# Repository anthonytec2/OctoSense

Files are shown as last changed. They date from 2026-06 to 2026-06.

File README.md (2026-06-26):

<!-- ======================= OctoSense ======================= -->
<p align="center">
  OctoSense
</p>

<p align="center"><b>Self-Supervised Learning for Multimodal Robot Perception</b></p>

<p align="center">
  
  
  
  
</p>

<p align="center">
  <video src="https://github.com/user-attachments/assets/d7269059-0989-4554-a36d-4d6e72473253"
         autoplay loop muted playsinline controls width="100%">
    <a href="https://huggingface.co/datasets/anthonytec2/OctoSense/resolve/main/assets/hero.mp4">Watch the OctoSense overview video</a>
  </video>
</p>

---

**OctoSense** is a multimodal dataset spanning a car, boat, and quadruped on a shared sensor platform. The
bulk is large-scale **driving**: **59 hours / 2,474 km / 8.43 TB** of time-synchronized data from
**stereo RGB + event cameras, LiDAR, thermal, IMU, RTK-GPS, and the vehicle CAN bus**, recorded across
urban, suburban, and rural roads from sunrise to night and through degraded sensors, with
ground truth for **depth, optical flow, semantic segmentation, and ego-motion**. We also include
sequences recorded on a **boat** and a **Unitree quadruped** using the same sensor platform. Every sequence is
captured by a fully **open-source sensor platform** and processed with the pipeline in this repo.

> **Getting started with OctoSense data:** the
> [**getting-started notebook**](octosense_quickstart.ipynb) downloads a sequence and walks
> through every modality. Open it with **zero setup** in
> [Colab](https://colab.research.google.com/drive/11hBm5dH--7HueAFCKtaAFnDAJul-52fb?usp=sharing), or
> run it locally after the install below (activate the env first: `conda activate octosense`).
> 
> **The dataset (sensor specs, HDF5 schema, per-sequence metadata, and downloads) lives on the
> [Hugging Face dataset page](https://huggingface.co/datasets/anthonytec2/OctoSense).**
> This repository is the **tooling around it**: how the data is collected, visualized, and produced.

## Installation

OctoSense has two parts with separate environments:

- **Data acquisition + conversion**: the ROS 2 capture stack ([`OctoSense/`](OctoSense/)) and the
  raw-bag conversion run in a **custom-built Docker container** (ROS 2 Jazzy + source-built FFmpeg);
  only the raw-bag conversion in `data_processing/timesync/` needs the ROS 2 container. See
  **[OctoSense/README.md](OctoSense/README.md)** to build and run it.
- **Data loading + processing**: loading/visualizing the data, deriving flow, and the
  depth/segmentation ground-truth and semantic-search tooling run in the **conda env** below.

```bash
git clone https://github.com/anthonytec2/OctoSense.git
cd OctoSense
conda env create -f environment.yml      # installs Python, FFmpeg, and a CPU build of PyTorch
conda activate octosense
```

This installs a **CPU** build of PyTorch + torchcodec by default. On a **CUDA GPU** (faster video
decoding and model inference) reinstall the **GPU wheels** for torch, torchvision, and torchcodec
after activating, picking versions per the
[torchcodec compatibility table](https://github.com/meta-pytorch/torchcodec#compatibility-with-torch-versions):

```bash
pip install 'torch==2.12.*' 'torchvision==0.27.*' 'torchcodec>=0.14' \
  --index-url https://download.pytorch.org/whl/cu130
```

## Download the dataset

The full dataset (8+ TB) lives on the
[Hugging Face dataset page](https://huggingface.co/datasets/anthonytec2/OctoSense).
Use **`download_octosense.py`** (repo root) to grab a subset by platform, sequence, and modality,
and skip the raw event streams (`events.h5`, ~78% of each sequence's bytes):

```bash
pip install huggingface_hub

# all car sequences (everything)
python download_octosense.py --platform car --out ./octosense

# the same, but skip the raw event streams (events.h5, ~78% of the bytes)
python download_octosense.py --platform car --no-events

# one sequence, only the core LiDAR/IMU/GPS h5 + depth + segmentation
python download_octosense.py --sequence rosbag2_2026_01_04-13_51_24 --modalities data,depth,seg

# download_octosense.py just wraps huggingface_hub, so you can also use the HF CLI directly
hf download anthonytec2/OctoSense --repo-type dataset --local-dir ./octosense
```

`--modalities` picks from `data, events, captions, depth, seg, rgb, ir`.

Five entry points into OctoSense from this repository, start with the notebook:

### Start here: the quickstart notebook ([`octosense_quickstart.ipynb`](octosense_quickstart.ipynb))
The [getting-started notebook](octosense_quickstart.ipynb) downloads a sequence and walks
through every modality (LiDAR, stereo RGB, events, depth, segmentation, GPS, IMU, CAN, and captions).
Open it with **zero setup** in
[Colab](https://colab.research.google.com/drive/11hBm5dH--7HueAFCKtaAFnDAJul-52fb?usp=sharing), or run
it locally after the install above (activate the env first: `conda activate octosense`).

### Visualize a sequence ([`data_processing/viz/`](data_processing/viz/))

<p align="center">
  <video src="https://github.com/user-attachments/assets/0f6a7751-e6b5-42f4-a3f9-07839ff3b1ef"
         autoplay loop muted playsinline controls width="100%">
    Rerun viewer scrubbing an OctoSense sequence across every modality.
  </video>
</p>

Generate a **[Rerun](https://rerun.io)** recording from a downloaded sequence with the script below,
then open the resulting `.rrd` in the Rerun viewer to scrub every modality on one shared timeline
(LiDAR, stereo RGB, reconstructed event video, depth, GPS track, IMU, CAN signals, and captions) with
a bundled viewer layout:

```bash
python data_processing/viz/rerun_viz.py --dir <sequence_dir>
```

### Search the dataset in natural language ([`data_processing/sem_search/`](data_processing/sem_search/))

<p align="center">
  OctoSense semantic-search web UI
</p>
<p align="center"><sub>The <code>serve</code> web UI: a natural-language query returning ranked clips with scores and scene captions.</sub></p>

Every 5s of image sensor data is captioned and embedded into a hybrid **FAISS + BM25** index, so you can find moments
across all 2,474 km by description ("a car turning left at dusk", "wet road at night", "pedestrian
crossing"). Download the prebuilt index from the dataset and query it from the CLI
(CPU works; a GPU just speeds up the query encoder):

```bash
# 1) prebuilt search index (~700 MB) from the dataset
hf download anthonytec2/OctoSense --repo-type dataset --include "semantic_search/*" --local-dir ./octosense

# 2) natural-language query -> ranked sequences + timestamps (run from data_processing/)
cd data_processing
python -m sem_search.main query "a car turning left at dusk" --index-dir ../octosense/semantic_search

# 3) or browse results in a web UI (matching video clips in the browser at http://localhost:8000)
#    set DATA_BASE_PATH so the UI can play each result's clip (see note below)
DATA_BASE_PATH=./octosense/car python -m sem_search.main serve --index-dir ../octosense/semantic_search --port 8000
```

First run pulls the **Qwen3-Embedding** query encoder. Searching needs no video, but to **play the
matching clips** in the web UI, set the **`DATA_BASE_PATH`** env var to the dataset root that holds
`<session>/<bag>/{img_left.mp4, data.h5}` (e.g. `./octosense/car`); the clip/thumbnail endpoints read
`img_left.mp4` from there per request. Results can come from any sequence, so a clip only plays if
that sequence's `img_left.mp4` is present under `DATA_BASE_PATH` (others return 404; the text results
still show). For how the index is built, see the
**[`sem_search` stage details](data_processing/README.md)**.

### Collect your own data ([`OctoSense/`](OctoSense/))
Everything to reproduce the sensor platform and record your own synchronized data: the ROS 2 (Jazzy) capture
stack, **hardware PPS time-sync** (Teensy firmware + KiCad SyncBoard distributing a
pulse-per-second to every sensor), the mechanical **CAD**, the containerized capture environment, and
a web monitor to watch per-sensor health and start/stop recording.
**[Build and run instructions](OctoSense/README.md)**

<table align="center">
  <tr>
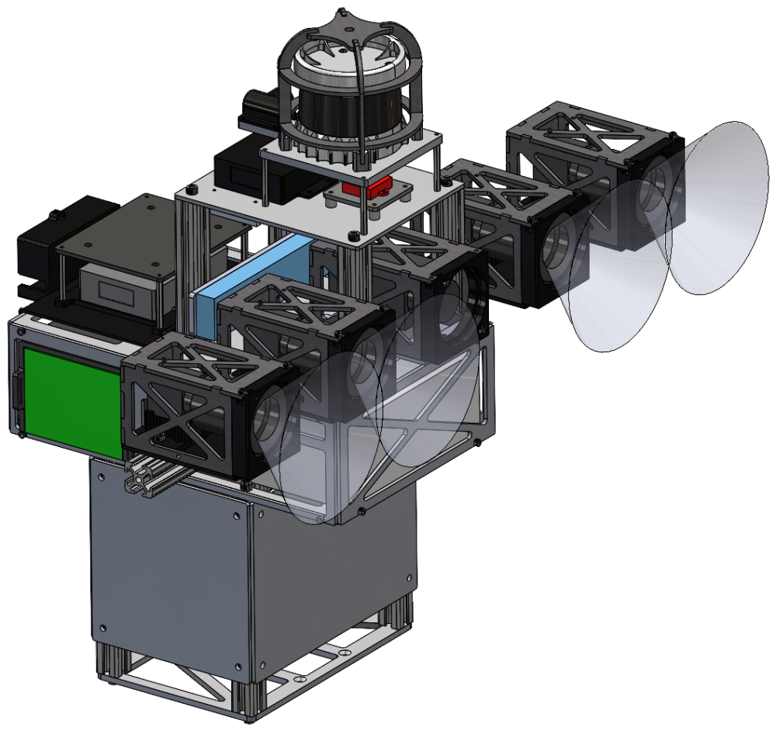
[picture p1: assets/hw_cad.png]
OctoSense sensor platform (CAD)
    <td align="center"></td>
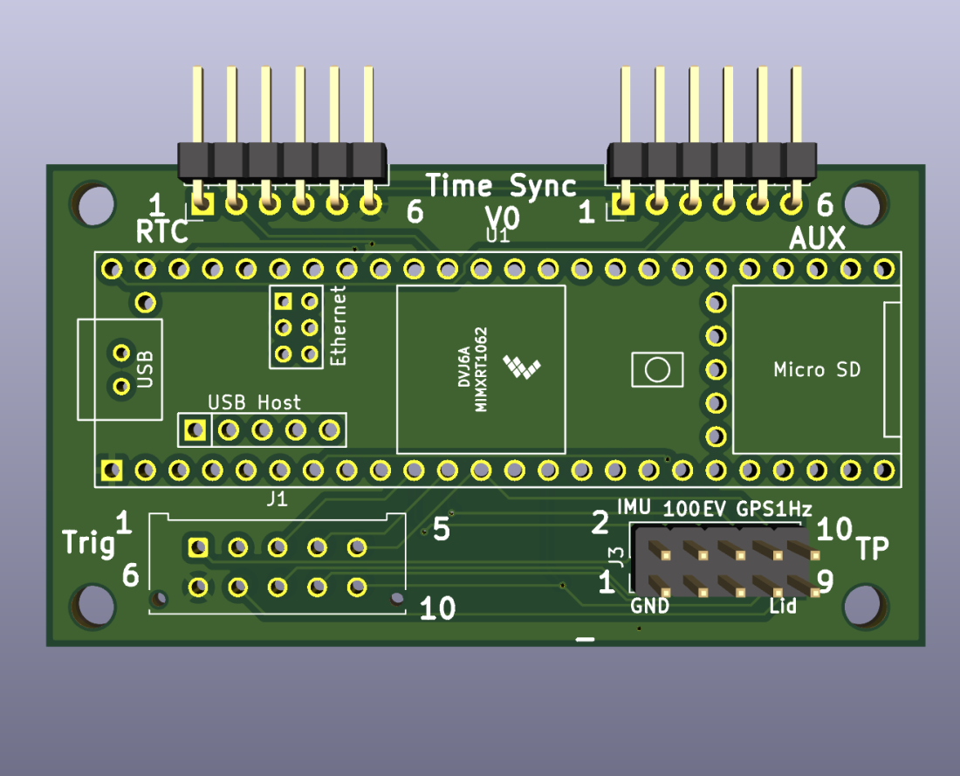
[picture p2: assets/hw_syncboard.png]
SyncBoard with the Teensy PPS clock
    <td align="center"></td>
  </tr>
  <tr>
    <td align="center"><sub>OctoSense Sensor Platform (CAD)</sub></td>
    <td align="center"><sub>Time Synchronization Custom PCB</sub></td>
  </tr>
</table>

### Process ROS2 Bags into OctoSense ([`data_processing/`](data_processing/))
The pipeline that turns a raw ROS 2 bag into the released sequences, as independent stages:
**`timesync`** (PPS clock-sync of all sensors to per-bag HDF5 + H.265 video), **`lidar_cal`**
(LiDAR/camera extrinsics), **`depth_gt`** (accumulated-LiDAR depth + derived ego-motion optical
flow), **`seg_gt`** (EoMT semantic labels), and **`sem_search`** (caption + embed to natural-language
search index). **[Per-stage details](data_processing/README.md)**

> This repo releases the **platform + data tooling only**. The multi-modal masked auto-encoder
> (**model, training, and dataloader code**) will be released at a later date.

## Citation
```bibtex
@misc{bisulco2026octosense,
  title        = {{OctoSense}: Self-Supervised Learning for Multimodal Robot Perception},
  author       = {Bisulco, Anthony and Wang, Jeremy and Daniilidis, Kostas and Balestriero, Randall and Chaudhari, Pratik},
  year         = {2026},
  howpublished = {Preprint},
}
```

## License
Released under the **[MIT License](LICENSE)**: free to use, modify, and redistribute with attribution;
provided "as is" without warranty. If you use OctoSense, please cite the paper above.

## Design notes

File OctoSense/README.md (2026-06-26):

# OctoSense — Data Collection

The data-collection stage of OctoSense: a ROS 2 (Jazzy) node that brings up a
multi-sensor platform, hardware-synchronizes it with a Teensy PPS trigger, and records
[rosbag2](https://github.com/ros2/rosbag2) (MCAP) datasets. It ships with a
small web UI for monitoring sensor health and starting/stopping recordings.

Sensors recorded here include event cameras, FLIR vision cameras, a FLIR
thermal camera, an Ouster LiDAR, a VectorNav IMU, u-blox GPS, and the vehicle CAN bus.

## Layout

```
OctoSense/
├── Dockerfile            # ROS 2 Jazzy + source-built FFmpeg image
├── run.sh                # build/run the container
├── entrypoint.zsh        # in-container: build the ws, then launch the controller in tmux
├── cfg/                  # udev rules (serial devices, CAN) + shell/tmux dotfiles
├── teensy/
│   └── pps_clock/        # Teensy MCU firmware: the PPS clock that hardware-syncs all sensors
├── SyncBoard/            # KiCad PCB (schematic + board + .pdf): distributes the Teensy PPS trigger to each sensor
├── CAD/                  # SolidWorks  parts for the sensor platform (camera bar, plates, cases)
└── data_collect/         # the ROS 2 data collection package
    ├── config/           # per-sensor configs + sensors_config.yaml (rates, health gates)
    ├── launch/           # system.launch.py brings up the whole sensor stack
    └── data_collect/
        ├── main.py                  # entry point: build controller + start web server
        ├── collection_controller.py # state machine: launch → validate → record
        ├── log_aggregator.py        # tails ROS output, polls topic rates, gates health
        ├── recorder_config.py       # the rosbag2 recorder topic list + parameters
        ├── web_server.py            # FastAPI control API (start/stop/shutdown/status)
        └── static/                  # the web UI (sensor table + recording controls)
```

## How it works

1. `main.py` builds a `CollectionController` and starts the FastAPI web server (`:8080`).
2. The controller runs `system.launch.py`, which brings up every sensor driver.
3. `LogAggregator` polls each sensor's topic rate (`ros2 topic hz`) and parses driver logs
   to track health. The controller waits until all *required* sensors hit spec, then reports
   `READY`.
4. On **Start Recording**, the rosbag2 `Recorder` is loaded into the container as a
   composable node, the bag file is confirmed on disk, and the Teensy PPS trigger is armed
   so all sensors capture on a common clock. **Stop** disarms the trigger, flushes, and
   unloads the recorder.

## Build and run

The data-collection container runs on the platform's host machine, where it can reach the physical sensors
(cameras, LiDAR, IMU, GPS, CAN).

**Prerequisites (host):** Docker, the udev rules from [`cfg/`](cfg/) installed (serial/CAN device
names), and, for the event cameras, the CenturyArks SilkyEvCam HAL plugin (see below).

```bash
# 1. Build the image (ROS 2 Jazzy + source-built FFmpeg + the capture workspace).
#    Run from this directory — the build context is OctoSense/ (it COPYs data_collect/, cfg/,
#    entrypoint.zsh). This is a large build (CUDA base + ~25 ROS repos + two colcon builds).
docker build -t octosense .

# 2. Run it. run.sh takes the image name.
ROSBAGS_DIR=$HOME/rosbags ./run.sh octosense
```

On start, `entrypoint.zsh` builds the `data_collect` package, then launches the collection
controller in tmux. Open the web UI at **`http://<host>:8080`** to watch per-sensor health and
start/stop recording. Recorded bags land in `ROSBAGS_DIR` on the host (mounted to `/rosbags`;
the recorder's path comes from `bag_output_dir` in `data_collect/config/sensors_config.yaml`).

**Runtime options** are passed through `run.sh` as `KEY=VALUE` args (it forwards them to the
container as `-e`):

```bash
./run.sh octosense ENABLE_GPS=false CAR_MODE=false PORT=8080
```

| variable | default | effect |
|---|---|---|
| `ENABLE_GPS` | `true` | `false` brings the stack up without GPS (`--no-enable-gps`) |
| `CAR_MODE` | `true` | `false` for non-vehicle rigs, e.g. boat/quadruped (`--no-car-mode`) |
| `HOST` | `0.0.0.0` | web-server bind address |
| `PORT` | controller default | web-server port |
| `CONFIG` | `sensors_config.yaml` | alternate sensor config path (in the container) |

## Hardware (build the sensor platform)

The physical platform is fully open: the sync firmware, the trigger PCB, and the mechanical CAD.

<table align="center">
  <tr>
    <td align="center">OctoSense sensor platform (CAD)</td>
    <td align="center">SyncBoard with the Teensy PPS clock</td>
  </tr>
  <tr>
    <td align="center"><sub>OctoSense Sensor Platform (CAD)</sub></td>
    <td align="center"><sub>Time Synchronization Custom PCB</sub></td>
  </tr>
</table>

**Teensy PPS clock** ([`teensy/pps_clock/`](teensy/pps_clock/)) is the firmware that generates the
pulse-per-second trigger distributed to every sensor. It targets a **Teensy 4.1** and uses the
Adafruit **RTClib** library. Compile `pps_clock.ino` to a `.hex` with the Teensy toolchain (the
Arduino IDE + [Teensyduino](https://www.pjrc.com/teensy/td_download.html), or `arduino-cli` with the
Teensy core), then flash it with [`teensy_loader_cli`](https://www.pjrc.com/teensy/loader_cli.html):

```bash
# compile to a .hex (arduino-cli with the Teensy core + Adafruit RTClib installed)
arduino-cli compile --fqbn teensy:avr:teensy41 --export-binaries teensy/pps_clock

# flash the exported .hex to the Teensy 4.1
teensy_loader_cli --mcu=TEENSY41 -v -w pps_clock.ino.hex
```

**SyncBoard** ([`SyncBoard/`](SyncBoard/)) is a KiCad PCB that fans the Teensy's PPS trigger out to
each sensor connector. Open `SyncBoard.kicad_pro` in KiCad to edit.

**CAD** ([`CAD/`](CAD/)) holds the SolidWorks parts and assemblies for the sensor platform (camera bar,
plates, cases).

## SilkyEvCam event cameras — proprietary HAL plugin

The stereo event cameras (CenturyArks **SilkyEvCam**) require CenturyArks'
**proprietary HAL plugin**, which is **not bundled in
this repo or image**. The open-source event-camera driver stack (`metavision_driver`,
`openeb_vendor`, `event_camera_*`) *is* built into the image, but the SilkyEvCam won't
enumerate until you install the plugin yourself. Download the installer from CenturyArks and
run it on the host, it installs the HAL plugin, tools, and udev rules:
- **https://centuryarks.com/en/download/** — e.g. `SilkyEvCam_Plugin_Installer_for_ubuntu_v5.2.0.zip`

> **Hardware-specific values** (camera serials, sensor IP addresses, network interface
> names, the CAN/serial udev rules in `cfg/`) are tuned to our platform. Adjust them in the
> configs and `cfg/` rules for your own hardware.

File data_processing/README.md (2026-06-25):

# OctoSense — `data_processing`

Turns raw OctoSense ROS 2 bags into the released multi-modal dataset: time-synchronized
per-bag HDF5 + camera video, plus the depth / segmentation ground-truth, the
semantic-search index, and visualization tooling.

```
data_processing/
├── timesync/      # raw ROS 2 bag → time-synced per-bag HDF5 (data + events) + camera video
├── lidar_cal/     # LiDAR ↔ camera extrinsic calibration
├── depth_gt/      # LiDAR depth + camera-motion optical-flow ground truth
├── seg_gt/        # EoMT semantic-segmentation ground truth
├── sem_search/    # caption + embed + FAISS/BM25 natural-language search index
└── viz/           # Rerun visualization of a processed sequence
```

Most stages run in the data-processing container image; the ROS 2 conversion in
`timesync/` additionally needs ROS 2 Jazzy + the `data_collect` workspace. `timesync` (GPU-accelerated
camera-video encoding), the GT stages, and **building** the search index (`sem_search ingest-all`)
need a GPU; **querying/serving** a built index runs on CPU.

## Setup

Every stage except the ROS 2 conversion in `timesync/` runs from the repo's Python environment,
installed once from the repo root (see the [main README](../README.md#installation)):

```bash
conda env create -f environment.yml && conda activate octosense   # bundles FFmpeg
# or:  pip install -r requirements.txt   (install FFmpeg yourself)
```

This single environment covers all of the stages below, including the GT generators
(`depth_gt`, `seg_gt`) and the semantic-search index. Notes:

- **`seg_gt`** downloads the EoMT (Cityscapes) weights via `transformers` on first run.
- **`sem_search ingest-all`** also needs a Gemma-4 VLM served at an OpenAI-compatible endpoint
  (passed via `--vllm-api-base`); querying/serving a built index needs neither. Start the captioner
  with vLLM (served under the name the client expects, `gemma4-captioner`):

  ```bash
  vllm serve google/gemma-4-31B-it --served-model-name gemma4-captioner --port 8000
  # then point ingest-all at it:
  python -m sem_search.main ingest-all --data-dir <root> --output-dir <index> \
      --vllm-api-base http://localhost:8000/v1
  ```
- **`timesync/`** runs in the ROS 2 (Jazzy) data-processing container — see [`../OctoSense/`](../OctoSense/).

All commands below are run from inside the relevant stage directory.

> **Internal vs. released file naming.** `timesync/` writes the per-bag HDF5 as
> `<bag_id>.h5` (e.g. `rosbag2_2026_01_04-13_51_24.h5`), and the downstream stages
> that consume it (**`lidar_cal/`, `depth_gt/`, `seg_gt/`**). In the **released dataset on Hugging Face that  same file is published as `data.h5`**. So to run these stages on downloaded sequences, point them at a bag dir where the main HDF5 is named `<bag_id>.h5` (rename or symlink
> `data.h5` to `<bag_id>.h5`); otherwise discovery finds no bags.

### Camera / IMU calibration (Kalibr)

The camera intrinsics + camera↔camera/IMU extrinsics that `timeSync` / `lidar_cal` consume are
solved with [Kalibr](https://github.com/ethz-asl/kalibr), run from a separate Docker image built
from our fork [anthonytec2/kalibr](https://github.com/anthonytec2/kalibr). The fork sets the
AprilGrid default `blackTagBorder` to 1: our tags use a 1-bit black border, and stock Kalibr
defaults to 2 and fails to detect them.

```bash
# 1. Build the Kalibr image
git clone https://github.com/anthonytec2/kalibr.git && cd kalibr
docker build -t kalibr -f Dockerfile_ros1_20_04 .

# 2. Prep a calibration bag (cam_cals/ bag for cam-cam, imu_cals/ bag for imu-cam):
python timesync/timeSync.py --bag <raw cal bag> --mode calibration   # -> processed cal h5
python timesync/cal_dump.py --dir <processed cal-bag dir>            # -> <dir>/calibration.bag

# 3. Solve a calibration (run whichever one you need):

# camera-to-camera (all 4 cams: stereo RGB + stereo event)
docker run --rm -v /data:/data kalibr bash -c \
  "source /catkin_ws/devel/setup.bash && rosrun kalibr kalibr_calibrate_cameras \
     --bag <dir>/calibration.bag --target calibrations/aprilgrid.yaml \
     --models pinhole-radtan pinhole-radtan pinhole-radtan pinhole-radtan \
     --topics /flir_cam_right /flir_cam_left /event_camera_right /event_camera_left \
     --dont-show-report"

# imu-to-camera (RGB cams only; --cams = a camchain trimmed to cam0/cam1)
docker run --rm -v /data:/data kalibr bash -c \
  "source /catkin_ws/devel/setup.bash && rosrun kalibr kalibr_calibrate_imu_camera \
     --bag <dir>/calibration.bag --target calibrations/aprilgrid.yaml \
     --cams <rgb-only camchain.yaml> --imu calibrations/imu.yaml"
```

`-v /data:/data` mounts the host data root (where the raw + processed bags live) into the
container; change the host side to wherever your data is stored.

---

## `timesync/` — raw bag → time-synchronized dataset

The core conversion. PPS-locked time-synchronizes every sensor (FLIR stereo RGB, event
cameras, infrared, Ouster LiDAR, IMU, GPS, CAN/radar) onto one common clock and writes the
per-bag HDF5 + encoded camera video. Runs as a 3-step pipeline per bag:

1. **`odomLidarDump.py`**: decode Ouster LiDAR/IMU packets into a `<bag>_lio` ROS 2 bag for odometry.
2. **RKO-LIO odometry** (ROS 2 launch, in the `data_collect` package): offline LiDAR-inertial odometry, recorded next to the processed bag.
3. **`timeSync.py --mode data`**: time-sync all sensors, attach calibration, fuse the LiDAR-odometry + GPS trajectory, and write `<bag>.h5`, `<bag>_events.h5`, `img_{left,right,infrared}.mp4`, `time_offset.npz`.

`python timeSync.py --bag <raw_bag> --mode {data|calibration} [--cal-map cal_map.yaml] [--lio-bag <odom>]`

| file | role |
|---|---|
| `timeSync.py` | entry point (`--mode data` for collection bags, `calibration` for calib bags) |
| `timeSync_process.py` | the per-sensor workers (event/RGB/IR/LiDAR/IMU/GPS/CAN) + HDF5 merge |
| `timeSyncUtil.py` | bag reading (`BagTopicReader`), processed-path resolution, logging |
| `timeSync_calibration.py` | PPS triger parsing and Kalman filter time sync |
| `timeSync_constants.py` | topic names, sensor rates, dataset roots, CAN/radar config |
| `odomLidarDump.py` | Ouster packet → PointCloud2/Imu decode for the odometry step |
| `cal_dump.py` | reconstruct event frames + dump a ROS 2 bag for camera/IMU calibration |
| `fuse_trajectory.py` | fuse RKO-LIO + GPS into the `/fused_traj` reference trajectory |

## `lidar_cal/` — LiDAR ↔ camera extrinsic calibration

Solves the LiDAR-to-left-camera extrinsics from a calibration-target bag: detects the
circular target center in both the image (AprilTag + PnP) and the LiDAR point cloud, then
robustly fits the rigid transform. Output `lidar_calibration_results.yaml` feeds the
calibration metadata used by `timesync`.

`python lidarCal.py --processed-dir <cal_bag_dir> --cam-name cam1`

| file | role |
|---|---|
| `lidarCal.py` | entry point: orchestrates detection + extrinsic solve, writes the results yaml |
| `image_detection.py` | circle-center detection in the camera image (Kalibr intrinsics, AprilTag/PnP) |
| `lidar_detection.py` | circle-center detection in the LiDAR cloud (plane fit + circle fit) |
| `robust_matching.py` | robust / circle-optimized extrinsic solve |
| `viz_utils.py` | detection-overlay frames + quicklook video |

## `depth_gt/` — LiDAR depth (and optical-flow) ground truth

Accumulates deskewed Ouster scans in the map frame, voxel-filters for map consistency,
masks dynamic objects with YOLO segmentation, and z-buffers into the rectified-left camera
to produce a dense per-frame depth map (uint16 cm). Optical flow is then re-derived from
depth + camera motion.

```
python accum_depth_ds.py --raw_h5 <bag>.h5 --out <dir>        # → <bag>_gt.h5  (depth_cm)
python derive_flow.py    --depth_h5 <bag>_gt.h5 --out flow.h5 # → flow_uv (int16 fixed-point)
```

| file | role |
|---|---|
| `accum_depth_ds.py` | entry point: scan accumulation → map filter → dynamic mask → z-buffer → depth H5 |
| `geometry.py` | rectified intrinsics, rectify grid, viewport culling, map-consistency filter, GPU projection/z-buffer |
| `masking.py` | `DynamicMasker` — YOLO-seg dynamic-object masks (person/vehicle) |
| `derive_flow.py` | camera-motion-induced optical flow from depth + poses (rectified-left; swappable to event/IR) |

## `seg_gt/` — semantic-segmentation ground truth

Runs EoMT (Cityscapes DINOv2-L-1024, 19 classes) on the rectified-left camera at the LiDAR
10 Hz frame times, writing a per-bag `semantic.h5` (uint8 class maps) with CLAHE
preprocessing.

`python run_seg.py --data_dir <root> [--bags sess/<bag> …] [--output_dir <out>]`

| file | role |
|---|---|
| `run_seg.py` | entry point: bag discovery, frame indexing, EoMT inference, `semantic.h5` writer |
| `perception_utils.py` | calibration loading (left undistort+rectify maps), CLAHE, bag discovery, resume check |
| `models/seg_eomt.py` | EoMT HuggingFace wrapper (`tue-mps/cityscapes_semantic_eomt_large_1024`) |

## `sem_search/` — natural-language video search

Captions each window (Gemma via a vLLM server), embeds the captions (Qwen3-Embedding-8B),
and builds a hybrid FAISS + BM25 index, served behind a FastAPI app for natural-language
search over the dataset.

```
# ingest-all needs the captioner VLM running first (served as gemma4-captioner):
vllm serve google/gemma-4-31B-it --served-model-name gemma4-captioner --port 8000

python -m sem_search.main ingest-all --data-dir <root> --output-dir <index> --vllm-api-base http://localhost:8000/v1
DATA_BASE_PATH=<dataset_root>/car python -m sem_search.main serve --index-dir <index> --port 8000   # FastAPI web UI
python -m sem_search.main query "a car turning left at dusk" --index-dir <index>   # CLI search, no server
```

> **`DATA_BASE_PATH` (clip playback).** Search/`query` need no video. The web UI's inline player and
> thumbnails, however, fetch each result's clip from `$DATA_BASE_PATH/<session>/<bag>/img_left.mp4`
> (and read `data.h5` there for frame timing). Set `DATA_BASE_PATH` to the dataset root that contains
> the `<session>/<bag>/` sequence dirs (defaults to `/data/rosbags/hf_staging_octosense`). A result
> only plays if its sequence's `img_left.mp4` exists under that root; missing ones return 404 while the
> text results still render.

| path | role |
|---|---|
| `main.py` | CLI: `ingest-all` / `serve` / `query` |
| `text_encoder.py` | Qwen3 query/caption text embedding |
| `processing/ingestion.py` | scan dataset → windows → captions → embeddings → index |
| `processing/embedder.py` | caption + embedding generation (VLM prompts, telemetry) |
| `processing/prompts.py`, `processing/telemetry.py`, `processing/metadata.py` | prompt templates, run telemetry, window metadata |
| `serving/search_api.py` | FastAPI app: hybrid retrieval + clip extraction endpoints |
| `serving/diversity.py` | per-sequence diversity reranking |
| `serving/window_merger.py` | merge adjacent result windows into clips |
| `serving/clip_extractor.py` | stream-copy H.265 clip extraction with ffmpeg |
| `serving/webui/` | static web UI |

## `viz/` — Rerun visualization

Renders a processed bag (LiDAR clouds, camera + reconstructed event video, GPS, IMU, car
signals, captions) into a single `.rrd` on a shared timeline, with a bundled viewer layout.
Windowed by default for speed; `--full` for the whole ~10-min sequence.

`python rerun_viz.py --dir <processed_bag_dir> [--start S --end E | --full]`

| file | role |
|---|---|
| `rerun_viz.py` | entry point: logs all streams to `rerun_data.rrd`, bundles the blueprint |
| `octosense.rbl` | saved Rerun viewer layout |

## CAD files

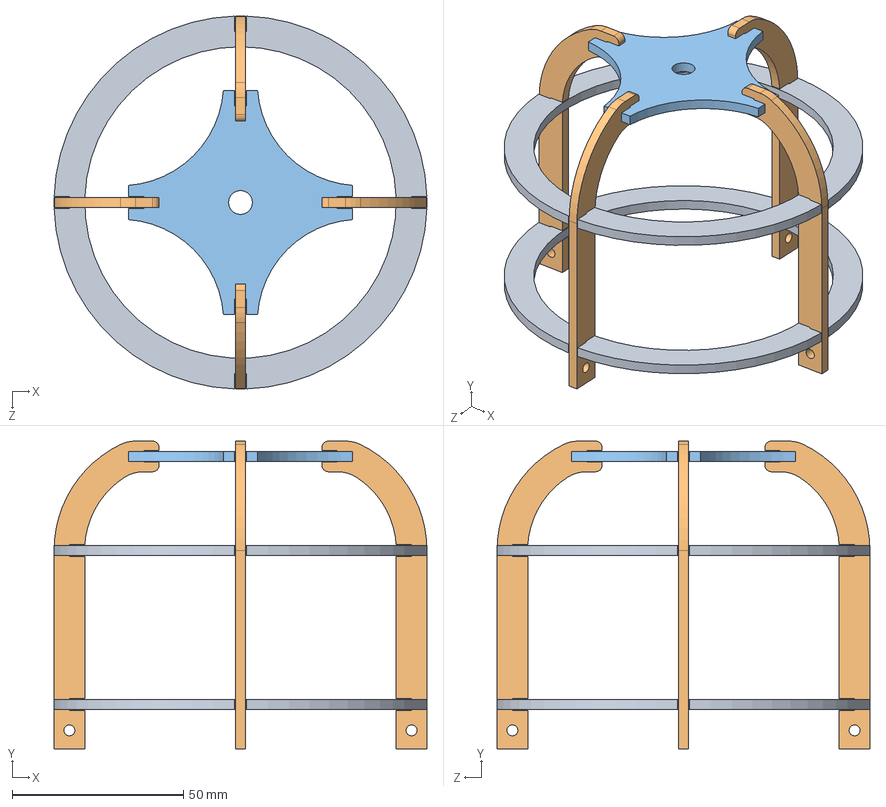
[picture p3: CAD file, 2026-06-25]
OctoSense/CAD/Ouster Cage Assembly V2.SLDASM
109.0 x 90.0 x 109.0 mm
Cage Connector Plate V2
Vertical Cage Member V2 x 4
Cage Ring V2 x 2

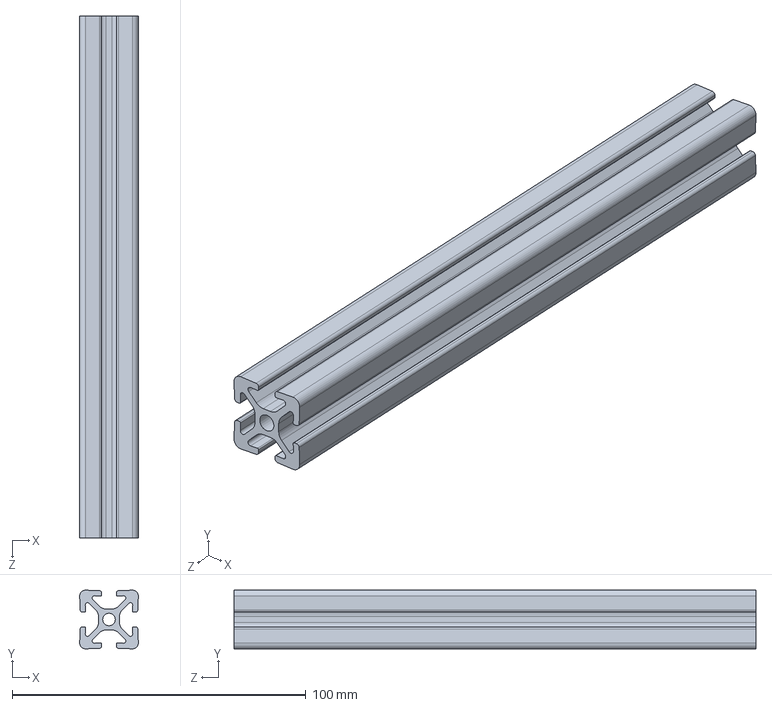
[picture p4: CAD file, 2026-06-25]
OctoSense/CAD/Metric 80-20.SLDPRT
20.0 x 20.0 x 177.8 mm

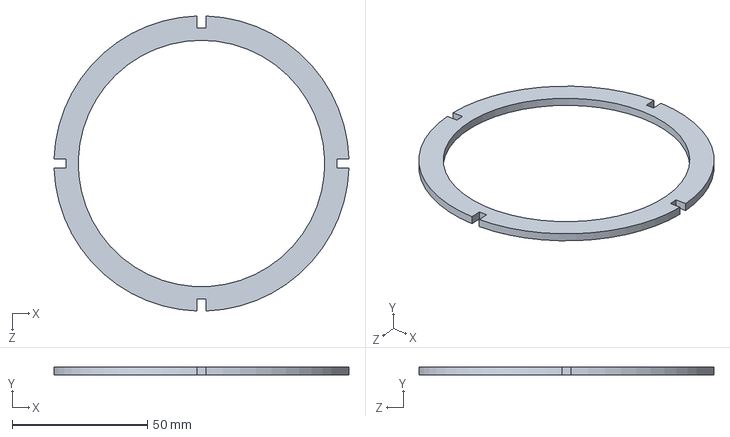
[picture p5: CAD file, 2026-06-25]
OctoSense/CAD/Cage Ring V2.SLDPRT
108.9 x 3.00 x 108.9 mm

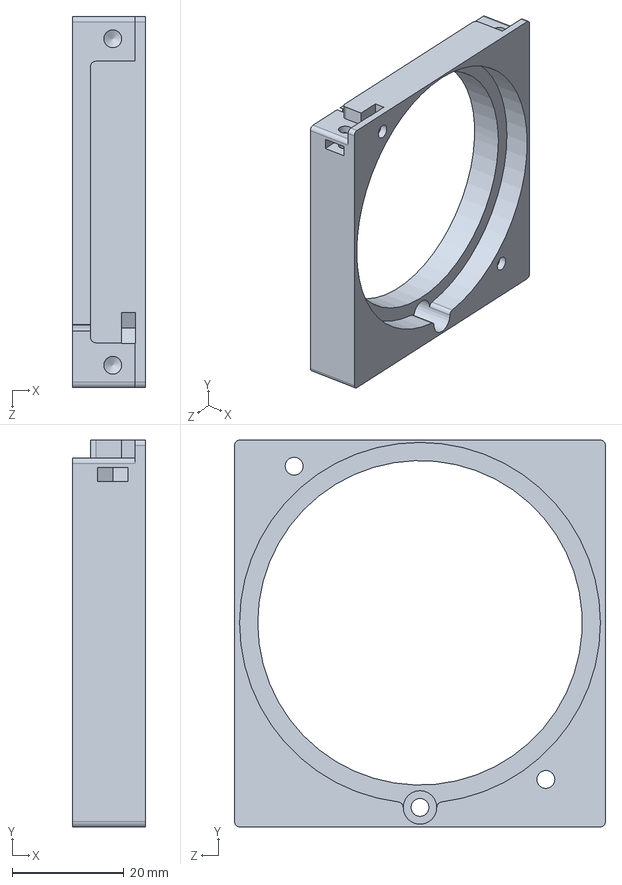
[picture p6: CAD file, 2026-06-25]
OctoSense/CAD/Camera Front Case Plate.SLDPRT
13.0 x 69.2 x 66.3 mm

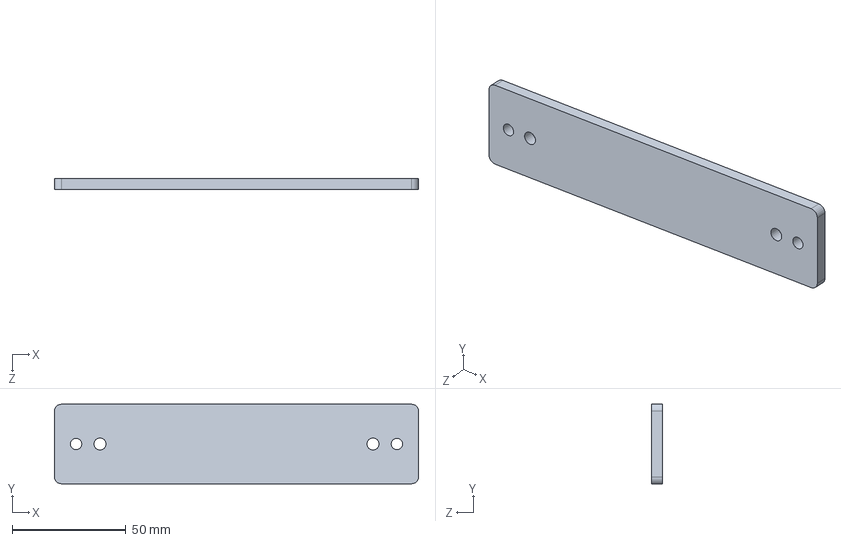
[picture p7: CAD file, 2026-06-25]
OctoSense/CAD/Power and Purple Board Plate.SLDPRT
160.0 x 35.0 x 4.76 mm

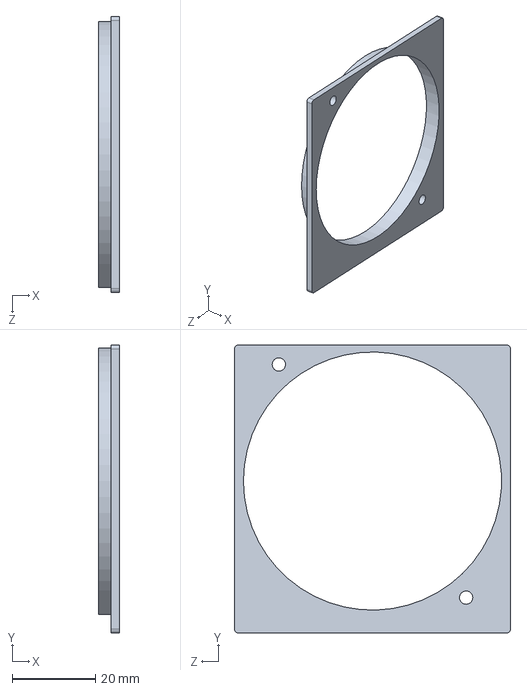
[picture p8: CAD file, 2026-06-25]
OctoSense/CAD/IR Filter Clamp.SLDPRT
5.00 x 69.2 x 66.3 mm

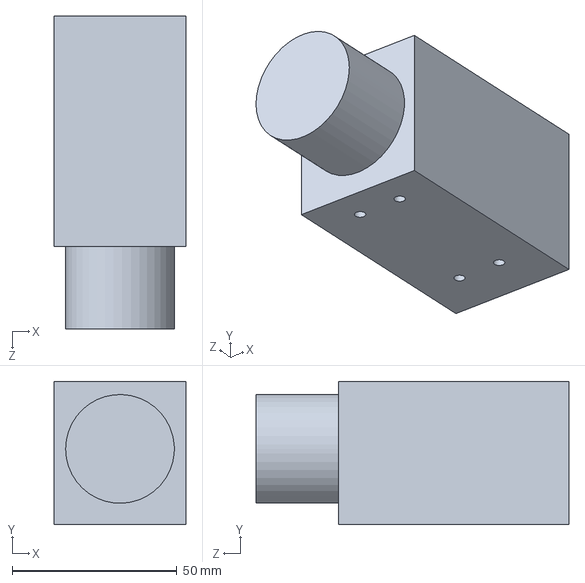
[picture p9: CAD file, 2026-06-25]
OctoSense/CAD/Mock Thermal Camera.SLDPRT
40.0 x 43.5 x 95.0 mm

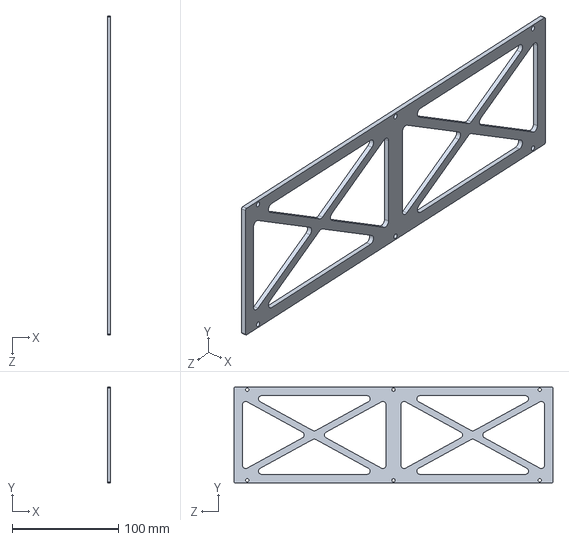
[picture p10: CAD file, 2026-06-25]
OctoSense/CAD/Right Side Sensor Tower Plate.SLDPRT
3.17 x 90.0 x 300.0 mm

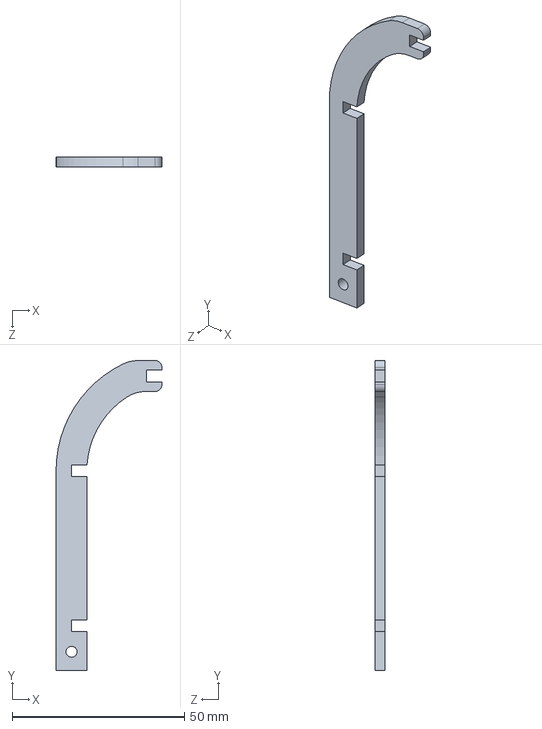
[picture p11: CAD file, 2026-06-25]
OctoSense/CAD/Vertical Cage Member V2.SLDPRT
30.7 x 90.0 x 3.00 mm

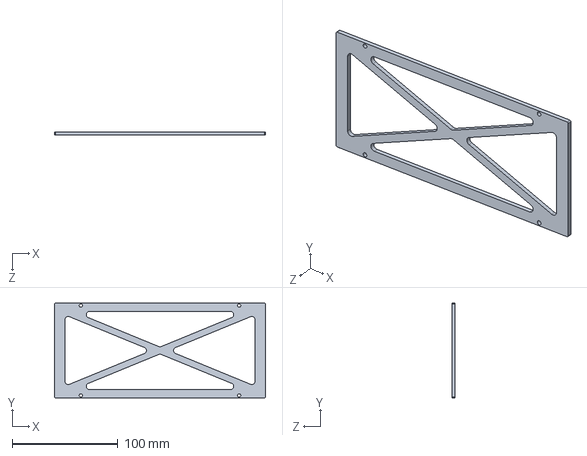
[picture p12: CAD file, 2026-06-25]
OctoSense/CAD/Front and Back Sensor Suite Plate.SLDPRT
200.0 x 90.0 x 3.17 mm

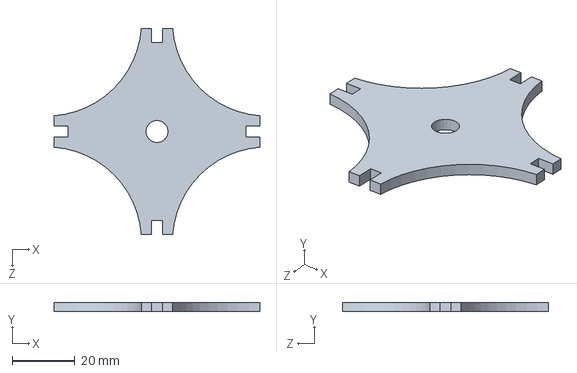
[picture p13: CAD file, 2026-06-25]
OctoSense/CAD/Cage Connector Plate V2.SLDPRT
65.5 x 3.00 x 65.5 mm

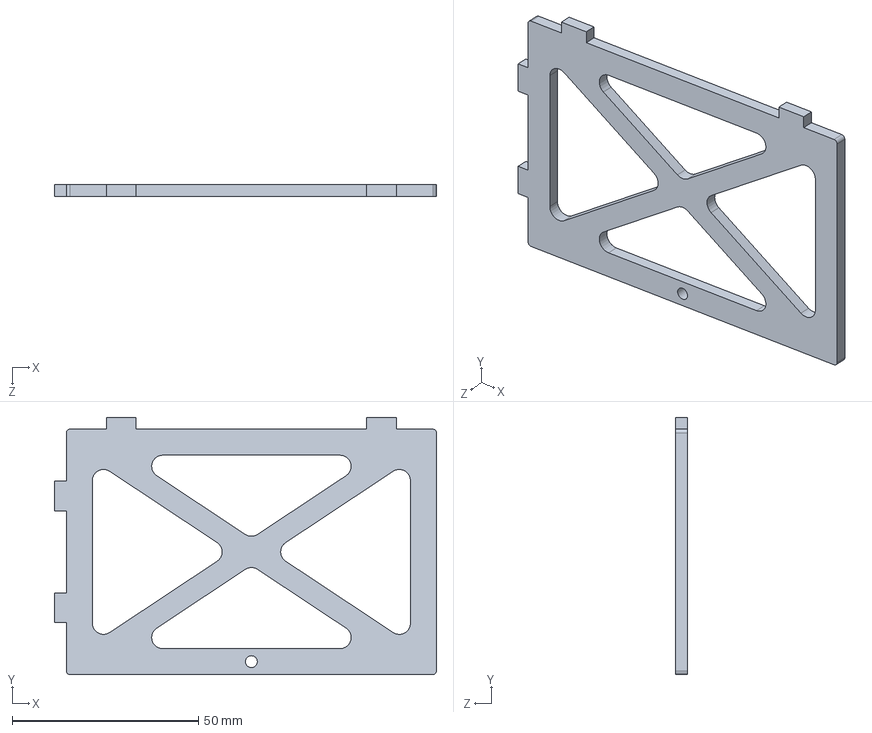
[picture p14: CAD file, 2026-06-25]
OctoSense/CAD/Side Camera Case.SLDPRT
102.7 x 69.2 x 3.17 mm

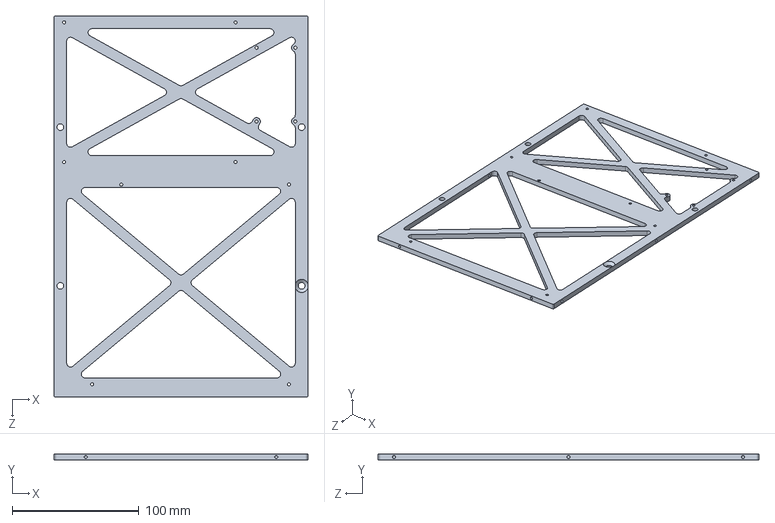
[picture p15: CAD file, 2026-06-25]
OctoSense/CAD/Sensor Suite Base Plate.SLDPRT
200.0 x 4.76 x 300.0 mm

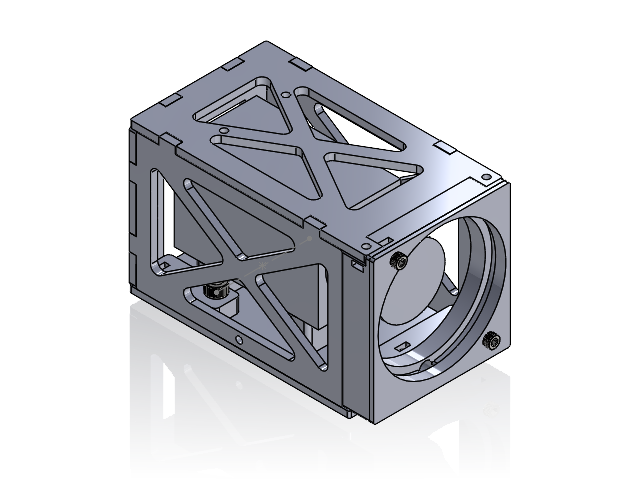
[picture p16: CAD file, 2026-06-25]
OctoSense/CAD/Thermal Camera Case.SLDASM
Thermal Camera Base
Side Camera Case x 2
Back Camera Case
Top Camera Case
Mock Thermal Camera
Camera Front Case Plate
IR Filter Clamp
91290A228_Black-Oxide Alloy Steel Socket Head Screw x 2
M3 91290A115_Black-Oxide Alloy Steel Socket Head Screw x 4

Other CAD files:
OctoSense/CAD/Camera Case.SLDASM
OctoSense/CAD/Camera Stack.SLDASM
OctoSense/CAD/Event Camera Case.SLDASM
OctoSense/CAD/Back Sensor Suite Plate.SLDPRT
OctoSense/CAD/80-20 Camera Bar.SLDPRT
OctoSense/CAD/91290A228_Black-Oxide Alloy Steel Socket Head Screw.SLDPRT
OctoSense/CAD/93115K871_Load-Rated Threaded Bumper.SLDPRT
OctoSense/CAD/93655A225_Male-Female Threaded Hex Standoff.SLDPRT
OctoSense/CAD/Back Camera Case.SLDPRT
OctoSense/CAD/Battery Case.SLDPRT
OctoSense/CAD/Buck Converter Plate.SLDPRT
OctoSense/CAD/Cage Mount V2.SLDPRT
OctoSense/CAD/Camera Base.SLDPRT
OctoSense/CAD/Car Mount.SLDPRT
OctoSense/CAD/Components Plate.SLDPRT
OctoSense/CAD/IMU Plate.SLDPRT
OctoSense/CAD/Left Side Sensor Tower Plate.SLDPRT
OctoSense/CAD/M3 91290A115_Black-Oxide Alloy Steel Socket Head Screw.SLDPRT
OctoSense/CAD/Mock Antenna.SLDPRT
OctoSense/CAD/Mock Battery.SLDPRT
OctoSense/CAD/Mock Cameras.SLDPRT
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

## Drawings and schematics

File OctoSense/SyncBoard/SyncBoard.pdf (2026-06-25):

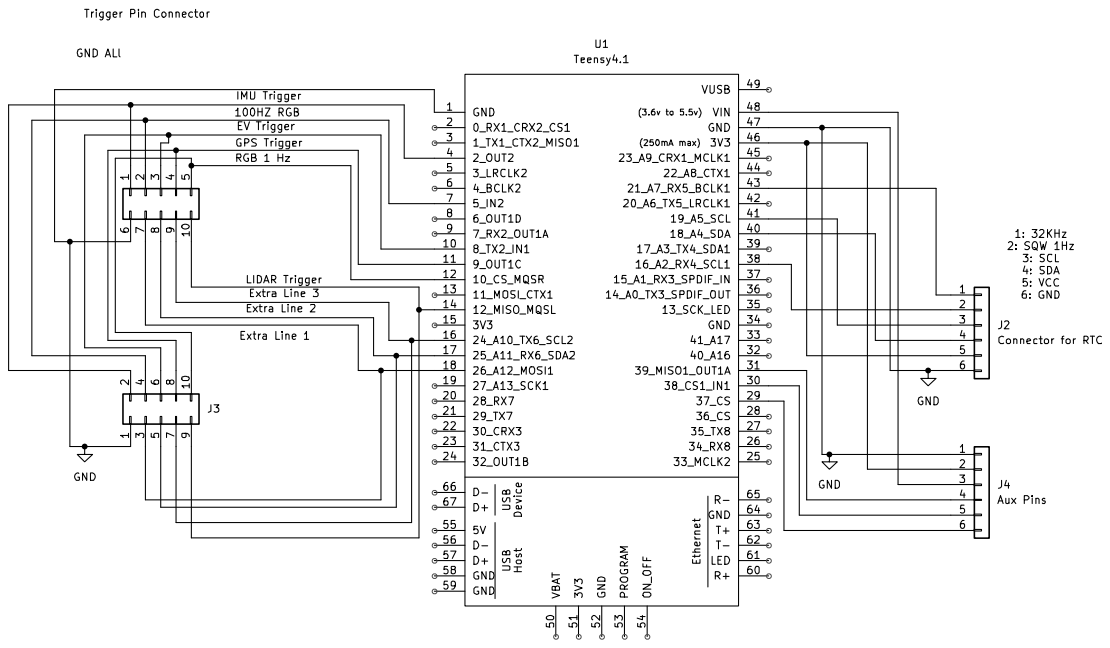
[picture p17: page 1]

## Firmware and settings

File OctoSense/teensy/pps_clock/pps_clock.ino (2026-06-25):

#include <Wire.h>
#include "RTClib.h"

#define SQW_PIN 16 // RTC Clock Pin

RTC_DS3231 rtc;
const int PIN_IMU      = 2;   // IMU PPS output
const int PIN_RGB_L    = 5;   // 100Hz RGB left (continuous)
const int PIN_EVENT    = 8;   // Event camera PPS output (shares the wide pulse)
const int PIN_RGB_1HZ  = 24;  // RGB 1Hz PPS output
const int PIN_LIDAR    = 12;  // Lidar PPS output (shares the wide pulse)

// Constants
const int PPS_PULSE_TICKS = 2;        // 10ms pulse width for standard pulses

// Timers
IntervalTimer timer100Hz; // Generates 100 Hz synced to external PPS

// State variables
volatile uint16_t tickCount = 0;
volatile bool rgbState = LOW;
volatile bool ppsEventActive = false;          // Tracks first IMU/RGB_1HZ 10ms pulse window
volatile bool widePulseActive = false;         // Tracks EVENT/LIDAR wide pulse window
volatile bool secondPulseActive = false;
volatile uint8_t ppsIndex = 0;                 // Counts PPS pulses since START (1..), Note this is the rollover for UID resync
volatile uint16_t widePulseWidthTicks = 0;     // Per-PPS EVENT/LIDAR pulse width (ticks)
volatile bool secondPulseScheduled = false;    // Whether a second pulse is scheduled for IMU/RGB_1HZ this PPS
volatile uint16_t secondPulseStartTick = 0;    // Start tick for the second pulse (IMU/RGB_1HZ)
volatile uint16_t secondPulseEndTick = 0;      // End tick for the second pulse (IMU/RGB_1HZ)
volatile bool systemActive = false;
volatile bool rtcPulseDetected = false;
volatile uint8_t rtcTicksUntilStart = 0;       // Countdown: wait for N RTC ticks before activating PPS

void setup() {
  Serial.begin(115200);
  Serial.println("External PPS Generator Ready");
  Serial.println("Commands: START, STOP, STATUS");

  Wire.begin();
  rtc.begin();

  // Configure DS3231 SQW to 1Hz
  rtc.writeSqwPinMode(DS3231_SquareWave1Hz);

  // Configure pins
  pinMode(PIN_IMU, OUTPUT);
  pinMode(PIN_RGB_L, OUTPUT);
  pinMode(PIN_EVENT, OUTPUT);
  pinMode(PIN_RGB_1HZ, OUTPUT);
  pinMode(PIN_LIDAR, OUTPUT);
  pinMode(SQW_PIN, INPUT_PULLUP);

  // Initialize LOW
  digitalWriteFast(PIN_IMU, LOW);
  digitalWriteFast(PIN_RGB_L, LOW);
  digitalWriteFast(PIN_EVENT, LOW);
  digitalWriteFast(PIN_RGB_1HZ, LOW);
  digitalWriteFast(PIN_LIDAR, LOW);

  // Start 100Hz timer immediately for RGB_L (will be synced to PPS when START is issued)
  timer100Hz.begin(timer100HzISR, 5000); // 5ms intervals
  timer100Hz.priority(1);

  // Attach PPS interrupt immediately so we can always phase-align 100Hz to PPS
  attachInterrupt(digitalPinToInterrupt(SQW_PIN), rtcPulseISR, RISING);
}

void loop() {
  // Handle serial commands
  if (Serial.available()) {
    String command = Serial.readStringUntil('\n');
    command.trim();
    command.toUpperCase();

    if (command == "START") {
      startPPSGenerator();
    }
    else if (command == "STOP") {
      stopPPSGenerator();
    }
    else if (command == "STATUS") {
      Serial.println(systemActive ? "Status: RUNNING" : "Status: STOPPED");
    }
    else {
      Serial.println("Unknown command. Use: START, STOP, or STATUS");
    }
  }

  // Check for RTC pulse (always align 100Hz to PPS)
  if (rtcPulseDetected) {
    rtcPulseDetected = false;

    if (systemActive) {
      // If still waiting for initial RTC ticks, count down
      if (rtcTicksUntilStart > 0) {
        rtcTicksUntilStart--;
        Serial.print("Waiting for RTC tick ");
        Serial.print(4 - rtcTicksUntilStart);
        Serial.println(" of 4...");

        // Once countdown reaches 0, start generating PPS pulses
        if (rtcTicksUntilStart == 0) {
          Serial.println("RTC synchronized - activating PPS pulses");
        }
      } else {
        // Normal PPS pulse generation
        handleExternalPPS();
      }
    } else {
      // Even when not active, keep 100Hz aligned to PPS
      ppsSyncOnly();
    }
  }
}

// Control functions
void startPPSGenerator() {
  if (!systemActive) {
    systemActive = true;
    rtcTicksUntilStart = 4;  // Wait for 4 RTC ticks before activating PPS

    // Attach interrupt to external RTC pulse (rising edge)
    attachInterrupt(digitalPinToInterrupt(SQW_PIN), rtcPulseISR, RISING);

    Serial.println("External PPS Generator STARTED - waiting for 4 RTC ticks");
  } else {
    Serial.println("Already running");
  }
}

void stopPPSGenerator() {
  if (systemActive) {
    systemActive = false;

    // Force PPS pins LOW (but leave RGB_L running)
    digitalWriteFast(PIN_IMU, LOW);
    digitalWriteFast(PIN_EVENT, LOW);
    digitalWriteFast(PIN_RGB_1HZ, LOW);
    digitalWriteFast(PIN_LIDAR, LOW);

    // Reset state
    tickCount = 0;
    rgbState = LOW;
    ppsEventActive = false;
    secondPulseActive = false;
    widePulseActive = false;
    ppsIndex = 0;
    widePulseWidthTicks = 0;
    secondPulseScheduled = false;
    secondPulseStartTick = 0;
    secondPulseEndTick = 0;
    rtcPulseDetected = false;
    rtcTicksUntilStart = 0;

    Serial.println("External PPS Generator STOPPED");
  } else {
    Serial.println("Already stopped");
  }
}

// RTC pulse interrupt handler (called on rising edge of external 1Hz signal)
void rtcPulseISR() {
  // Always capture PPS edges so we can keep timers aligned even when stopped
  rtcPulseDetected = true;
}

// Keep 100Hz aligned to PPS without generating PPS pulses on other pins
void ppsSyncOnly() {
  // Base level at PPS boundary
  rgbState = HIGH;
  digitalWriteFast(PIN_RGB_L, HIGH);

  // Re-sync 100Hz timer phase to PPS
  timer100Hz.end();
  timer100Hz.begin(timer100HzISR, 5000); // 5ms intervals
  timer100Hz.priority(1);
}

// Handle external PPS trigger
void handleExternalPPS() {
  // First, align continuous signal (100Hz) to this PPS edge
  ppsSyncOnly();

  // Immediately set all PPS pins HIGH (concurrent start)
  digitalWriteFast(PIN_IMU, HIGH);
  digitalWriteFast(PIN_EVENT, HIGH);
  digitalWriteFast(PIN_RGB_1HZ, HIGH);
  digitalWriteFast(PIN_LIDAR, HIGH);

  // Reset counters and state
  tickCount = 0;
  rgbState = HIGH;
  ppsEventActive = true;
  widePulseActive = true;
  secondPulseActive = false;

  // Increment PPS index (first PPS after START will be index 1)
  ppsIndex++;

  // Configure EVENT/LIDAR pulse width for first 6 PPS pulses: width = 20ms + 10ms * i (i = 1..6)
  // After that, revert to standard 10ms (2 ticks)
  if (ppsIndex <= 6) {
    widePulseWidthTicks = 4 + (2 * ppsIndex); // (4+2i) ticks => 30..80ms
  } else {
    widePulseWidthTicks = PPS_PULSE_TICKS; // standard 10ms
  }

  // For IMU and RGB_1HZ, schedule a second pulse for first 6 PPS pulses
  // Spacing is 20ms + 10ms * i measured from the END of the first pulse to the START of the second pulse
  if (ppsIndex <= 6) {
    secondPulseStartTick = PPS_PULSE_TICKS + 4 + (2 * ppsIndex); // end of first pulse + (4+2i) ticks spacing
    secondPulseEndTick = secondPulseStartTick + PPS_PULSE_TICKS; // 10ms duration
    secondPulseScheduled = true;
  } else {
    secondPulseScheduled = false;
  }

  // Timer has already been synchronized in ppsSyncOnly()
}

// 100Hz timer ISR
void timer100HzISR() {
  // Always toggle RGB_L for continuous 100Hz signal
  rgbState = !rgbState;
  digitalWriteFast(PIN_RGB_L, rgbState);

  // Only handle PPS-related timing if system is active
  if (!systemActive) return;

  tickCount++;

  // Handle EVENT/LIDAR wide pulse
  if (widePulseActive && tickCount >= widePulseWidthTicks) {
    digitalWriteFast(PIN_EVENT, LOW);
    digitalWriteFast(PIN_LIDAR, LOW);
    widePulseActive = false;
  }

  // Handle initial IMU and RGB_1HZ pulses after standard 10ms
  if (ppsEventActive && tickCount >= PPS_PULSE_TICKS) {
    digitalWriteFast(PIN_IMU, LOW);
    digitalWriteFast(PIN_RGB_1HZ, LOW);
    ppsEventActive = false;
  }

  // Start scheduled second pulse for IMU and RGB_1HZ, if any
  if (secondPulseScheduled && !secondPulseActive && tickCount == secondPulseStartTick) {
    digitalWriteFast(PIN_IMU, HIGH);
    digitalWriteFast(PIN_RGB_1HZ, HIGH);
    secondPulseActive = true;
  }

  // End the second pulse after its duration
  if (secondPulseActive && tickCount >= secondPulseEndTick) {
    digitalWriteFast(PIN_IMU, LOW);
    digitalWriteFast(PIN_RGB_1HZ, LOW);
    secondPulseActive = false;
  }
}

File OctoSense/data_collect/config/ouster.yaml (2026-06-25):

# see: https://github.com/ouster-lidar/ouster-ros/blob/ros2/ouster-ros/config/driver_params.yaml
os_sensor:
  ros__parameters:
    sensor_hostname: '192.168.123.29'
    udp_dest: '192.168.123.51'
    lidar_mode: '2048x10'
    timestamp_mode: 'TIME_FROM_SYNC_PULSE_IN'
    udp_profile_lidar: 'RNG19_RFL8_SIG16_NIR16'
    metadata: ''
    lidar_port: 0
    imu_port: 0
    use_system_default_qos: false
    azimuth_window_start: 0
    azimuth_window_end: 360000
    persist_config: false
    attempt_reconnect: false
    dormant_period_between_reconnects: 1.0
    max_failed_reconnect_attempts: 2147483647

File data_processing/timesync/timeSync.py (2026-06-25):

"""
Main entry point for time synchronization processing.
Orchestrates calibration and processing of ROS2 bags.
"""
import sys
import numpy as np
import argparse
import logging
import os

from timeSyncUtil import BagTopicReader, get_processed_path, configure_file_logging
from timeSync_calibration import (
    CalibrationData,
    calibration_system_time, flir_time_offset, event_time_offset, imu_time_offset
)
from timeSync_constants import (
    FLIR_CAM0_TRIGGER_TOPIC, FLIR_CAM1_TRIGGER_TOPIC,
    EVENT_CAM0_TOPIC, EVENT_CAM1_TOPIC, IMU_TRIGGER_TOPIC,
    INFRARED_TRIGGER_TOPIC
)
from timeSync_process import process_bag

logger = logging.getLogger(__name__)
logging.basicConfig(level=logging.INFO, format='%(levelname)s:%(name)s:%(message)s')


def _restore(value):
    """Unwrap an .npz entry: 0-d object arrays (dicts / None) -> the original
    Python object; numeric arrays are returned as-is."""
    return value.item() if value.dtype == object else value


def get_time_offsets(bag_name) -> CalibrationData:
    """Extract time offset calibration from bag."""
    bag = BagTopicReader(bag_name)
    output_path, bn = get_processed_path(bag_name)
    os.makedirs(output_path, exist_ok=True)

    configure_file_logging(output_path)

    # Check if the time offset file exists
    time_offset_file = f"{output_path}/time_offset.npz"
    if os.path.exists(time_offset_file):
        # Load the saved offsets; keys match CalibrationData's fields exactly.
        data = np.load(time_offset_file, allow_pickle=True)
        fields = {k: _restore(data[k]) for k in data.files}
        logger.info("Loaded time offset objects from memory.")
        return CalibrationData(**fields)
    # Per-sensor calibration. Each spec maps the three CalibrationData fields
    # (device clock, main clock, filter) to its trigger topic, offset function,
    # and a label for the "missing topic" warning.
    calibrations = [
        ("device_clock_system", "master_clock_system", "system_filter",
         IMU_TRIGGER_TOPIC, lambda: calibration_system_time(bag),
         "IMU Topic for System Time Calibration"),
        ("device_clock_imu", "master_clock_imu", "imu_filter",
         IMU_TRIGGER_TOPIC, lambda: imu_time_offset(bag),
         "IMU Topic Messages"),
        ("device_clock_flir_0", "master_clock_flir_0", "flir_filter_0",
         FLIR_CAM0_TRIGGER_TOPIC, lambda: flir_time_offset(bag, FLIR_CAM0_TRIGGER_TOPIC),
         "FLIR 0 Topic Messages"),
        ("device_clock_flir_1", "master_clock_flir_1", "flir_filter_1",
         FLIR_CAM1_TRIGGER_TOPIC, lambda: flir_time_offset(bag, FLIR_CAM1_TRIGGER_TOPIC),
         "FLIR 1 Topic Messages"),
        ("device_clock_ev_0", "master_clock_ev_0", "event_filter_0",
         EVENT_CAM0_TOPIC, lambda: event_time_offset(bag, EVENT_CAM0_TOPIC),
         "EVENT 0 Topic Messages"),
        ("device_clock_ev_1", "master_clock_ev_1", "event_filter_1",
         EVENT_CAM1_TOPIC, lambda: event_time_offset(bag, EVENT_CAM1_TOPIC),
         "EVENT 1 Topic Messages"),
    ]

    # GPS is timestamped via the system-time calibration, so its fields stay None, legacy constraint
    fields = {"device_clock_gps": None, "master_clock_gps": None, "gps_filter": None}

    if INFRARED_TRIGGER_TOPIC in bag.topics_map:
        logger.info("Infrared camera will use system time calibration")

    for dc_key, mc_key, kf_key, topic, run_calibration, label in calibrations:
        if topic in bag.topics_map:
            fields[dc_key], fields[mc_key], fields[kf_key] = run_calibration()
        else:
            fields[dc_key] = fields[mc_key] = fields[kf_key] = None
            logger.warning("MISSING %s", label)
        logger.info('--------------------------------')

    np.savez(time_offset_file, **fields)
    logger.info(f"Saved time offset objects to {time_offset_file}")
    return CalibrationData(**fields)


if __name__ == "__main__":
    parser = argparse.ArgumentParser(description="Process a rosbag file for time sync.")
    parser.add_argument("--bag", type=str, required=True, help="Path to the rosbag file")
    parser.add_argument(
        "--mode",
        type=str,
        choices=["calibration", "data"],
        default="calibration",
        help=(
            "Processing mode. "
            "'calibration' (default) runs on calibration bags and writes full raw sensor data. "
            "'data' runs on data-collection bags and can attach calibration metadata and use LIO bags."
        ),
    )
    parser.add_argument(
        "--cal-map",
        type=str,
        default=None,
        help="Optional path to cal_map.yaml describing which calibration bags/metadata were used (data mode).",
    )
    parser.add_argument(
        "--lio-bag",
        type=str,
        default=None,
        help=(
            "Optional path to a LIO rosbag used for Ouster data "
            "(e.g. <session>/rosbag2_XXXX_lio). "
            "If not provided in data mode, raw Ouster packets from the main bag are used (fallback)."
        ),
    )
    args = parser.parse_args()

    # Infer defaults to make CLI simpler:
    # - cal_map.yaml lives one directory up from the bag folder
    # - LIO bag lives in the processed directory with suffix `_lio`
    bag_dir = os.path.dirname(os.path.normpath(args.bag))
    default_cal_map = os.path.join(bag_dir, "cal_map.yaml")
    cal_map_path = args.cal_map or default_cal_map

    processed_path, bn = get_processed_path(args.bag)
    processed_parent = os.path.dirname(processed_path.rstrip("/"))
    default_lio_bag = os.path.join(processed_parent, f"{bn}_lio", "odom")
    lio_bag_path = args.lio_bag or default_lio_bag

    try:
        calibration_data = get_time_offsets(args.bag)

        process_bag(
            args.bag,
            calibration_data,
            mode=args.mode,
            cal_map_path=cal_map_path,
            lio_bag=lio_bag_path,
        )
    except AssertionError as e:
        logger.error(f"Assertion failed: {e}")
        sys.exit(1)
    except Exception as e:
        logger.exception(f"Error processing bag: {e}")
        sys.exit(1)

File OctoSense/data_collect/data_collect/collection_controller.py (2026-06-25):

"""High-level orchestration for the ROS 2 data collection stack."""
from __future__ import annotations

import datetime
import logging
import os
import signal
import subprocess
import threading
import time
from enum import Enum
from pathlib import Path
from typing import Dict, List, Optional, Type
from zoneinfo import ZoneInfo

import serial

import rclpy
from composition_interfaces.srv import LoadNode, UnloadNode
from rclpy.parameter import Parameter as RclpyParameter
from rclpy.utilities import ok as rclpy_is_initialized  # ROS2 jazzy: is_initialized() -> ok()
from rosbag2_interfaces.srv import Pause as RecorderPause

from ament_index_python.packages import (
    PackageNotFoundError,
    get_package_share_directory,
)

from .log_aggregator import LogAggregator, SensorMetric, load_yaml, start_ros_launch
from .recorder_config import build_recorder_parameters

LOGGER = logging.getLogger(__name__)


class TeensyTrigger:
    """Simple helper to send trigger commands to the PPS Teensy."""

    def __init__(self, port: str, baudrate: int = 115200, timeout: float = 2.0):
        self.port = port
        self.baudrate = baudrate
        self.timeout = timeout
        self._break_keywords = ("started", "stopped", "status", "running", "already")

    def start(self) -> tuple[bool, str]:
        return self._send_command("START")

    def stop(self) -> tuple[bool, str]:
        return self._send_command("STOP")

    def status(self) -> tuple[bool, str]:
        return self._send_command("STATUS")

    def _send_command(self, command: str) -> tuple[bool, str]:
        try:
            with serial.Serial(self.port, self.baudrate, timeout=self.timeout) as ser:
                time.sleep(0.1)
                ser.reset_input_buffer()
                ser.write(f"{command}\n".encode())
                ser.flush()

                lines: List[str] = []
                deadline = time.time() + self.timeout
                while time.time() < deadline:
                    if ser.in_waiting:
                        raw = ser.readline().decode(errors="ignore").strip()
                        if raw:
                            lines.append(raw)
                            lowered = raw.lower()
                            if any(keyword in lowered for keyword in self._break_keywords):
                                break
                    else:
                        time.sleep(0.01)

                message = "; ".join(lines)
                return True, message if message else command
        except Exception as exc:  # pragma: no cover - hardware path
            return False, str(exc)


class ControllerState(str, Enum):
    INIT = "INIT"
    VALIDATING_SENSORS = "VALIDATING_SENSORS"
    READY = "READY"
    RECORDING = "RECORDING"
    FAILED = "FAILED"


class CollectionController:
    """Coordinate ROS launch lifecycle, bag recording, and monitoring."""

    def __init__(self, config_path: str):
        self.config_path = Path(config_path)
        self.config = load_yaml(self.config_path)
        self.state: ControllerState = ControllerState.INIT
        self.log_aggregator: Optional[LogAggregator] = None
        self.ros_process: Optional[subprocess.Popen] = None
        self.current_bag_info: Optional[Dict] = None
        self.last_failure: Optional[str] = None
        self.pps_config = self.config.get("pps", {})
        self.required_topics: List[str] = list(self.pps_config.get("required_topics", []))
        self.topic_check_interval = float(self.pps_config.get("topic_check_interval", 2.0))
        self.topic_ready_timeout = float(self.pps_config.get("topic_ready_timeout", 120.0))
        self.trigger_start_delay = float(self.pps_config.get("trigger_start_delay_s", 4.0))
        self.trigger_active = False
        self.trigger = TeensyTrigger(
            port=self.pps_config.get("serial_port", "/dev/teensy-pps"),
            baudrate=int(self.pps_config.get("serial_baudrate", 115200)),
            timeout=float(self.pps_config.get("serial_timeout", 2.0)),
        )

        recorder_config = self.config.get("recorder", {})
        self.component_container_name = recorder_config.get(
            "container_name", "sensor_container"
        )
        self.recorder_node_name = recorder_config.get("node_name", "recorder")
        self.recorder_include_hidden = bool(
            recorder_config.get("include_hidden_topics", True)
        )
        self.recorder_record_all = bool(recorder_config.get("record_all_topics", False))
        self.recorder_start_paused = bool(recorder_config.get("start_paused", False))
        self.recorder_storage_id = recorder_config.get("storage_id", "mcap")
        self.recorder_plugin = recorder_config.get(
            "plugin", "rosbag2_transport::Recorder"
        )
        self.recorder_package = recorder_config.get("package", "rosbag2_transport")
        self.recorder_component_id: Optional[int] = None
        self.component_service_timeout = float(
            self.config.get("component_service_timeout", 15.0)
        )
        self.enable_gps = self.config.get("enable_gps", True)
        self._component_service_lock = threading.Lock()

    # ------------------------------------------------------------------
    # Lifecycle
    # ------------------------------------------------------------------
    def startup_sequence(
        self,
        enable_gps: Optional[bool] = None,
        car_mode: bool = False,
    ):
        LOGGER.info("Starting collection controller sequence")
        self.state = ControllerState.VALIDATING_SENSORS
        system_cmd = self.config.get(
            "system_launch_cmd", "ros2 launch data_collect system.launch.py"
        )
        # Append enable_gps argument if specified (use parameter override or config value)
        enable_gps_value = enable_gps if enable_gps is not None else self.enable_gps
        enable_gps_str = "true" if enable_gps_value else "false"
        system_cmd = f"{system_cmd} enable_gps:={enable_gps_str}"
        # Append car_mode argument for socket CAN interface
        car_mode_str = "true" if car_mode else "false"
        system_cmd = f"{system_cmd} car_mode:={car_mode_str}"
        self.ros_process = start_ros_launch(system_cmd)

        self.log_aggregator = LogAggregator(self.config_path)
        self.log_aggregator.attach_process(self.ros_process)
        self.log_aggregator.controller_callback = self._on_sensor_failure
        self.log_aggregator.start_sensor_polling()

        sensor_ready_timeout = self.config.get("sensor_ready_timeout", 120)
        if not self._wait_for_sensors_ok(sensor_ready_timeout):
            self.state = ControllerState.FAILED
            raise RuntimeError("Sensors failed to reach expected rates")

        self.state = ControllerState.READY
        LOGGER.info("Collection controller ready")
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
